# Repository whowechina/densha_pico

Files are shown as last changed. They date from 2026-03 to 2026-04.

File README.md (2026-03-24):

# Densha pico - Densha De Go! Style Controller
[点这里可以切换到中文版](README_CN.md)



It's XXXXX.

## Features
* XXX
* YYY

## Thanks
Thanks to many respectful guys/companies who made their tools or materials free or open source (KiCad, OnShape, InkScape, Raspberry things).

Special thanks to community projects and developers.
And also these projects:
* RP_Silicon_KiCad: https://github.com/HeadBoffin/RP_Silicon_KiCad

## My Other Projects
You can check out my other cool projects.

               


* Popn Pico: https://github.com/whowechina/popn_pico
* IIDX Pico: https://github.com/whowechina/iidx_pico
* Chu Pico: https://github.com/whowechina/chu_pico
* Mai Pico: https://github.com/whowechina/mai_pico
* Diva Pico: https://github.com/whowechina/diva_pico
* AIC Pico: https://github.com/whowechina/aic_pico
* Groove Pico: https://github.com/whowechina/groove_pico
* Geki Pico: https://github.com/whowechina/geki_pico
* Musec Pico: https://github.com/whowechina/musec_pico
* Ju Pico: https://github.com/whowechina/ju_pico
* Bishi Pico: https://github.com/whowechina/bishi_pico
* Nos Pico: https://github.com/whowechina/nos_pico
* Voltex Pico: https://github.com/whowechina/voltex_pico
* Chord Pico: https://github.com/whowechina/chord_pico
* Dance Pico: https://github.com/whowechina/dance_pico
* Densha pico: https://github.com/whowechina/densha_pico

## **Disclaimer** ##
I made this project in my personal time with no financial benefit or sponsorship. I will continue to improve the project. I have done my best to ensure that everything is accurate and functional, there's always a chance that mistakes may occur. I cannot be held responsible for any loss of your time or money that may result from using this open source project. Thank you for your understanding.

## About the License
It's CC-NC. So DIY for yourself and for your friend, don't make money from it. And plagiarism that doesn’t even dare to mention the original author is not acceptable. Please note that pooling orders and group buying for raw materials is acceptable.Selling any leftover components at cost (without profit) is also acceptable.

If you're interested in buying from me, or for commercial use, please contact me (Discord, QQ group, Goofish).
* My Discord Invitation: https://discord.gg/M8f2PPQFEA
* QQ Group: 854535476
* Goofish: whowe12345

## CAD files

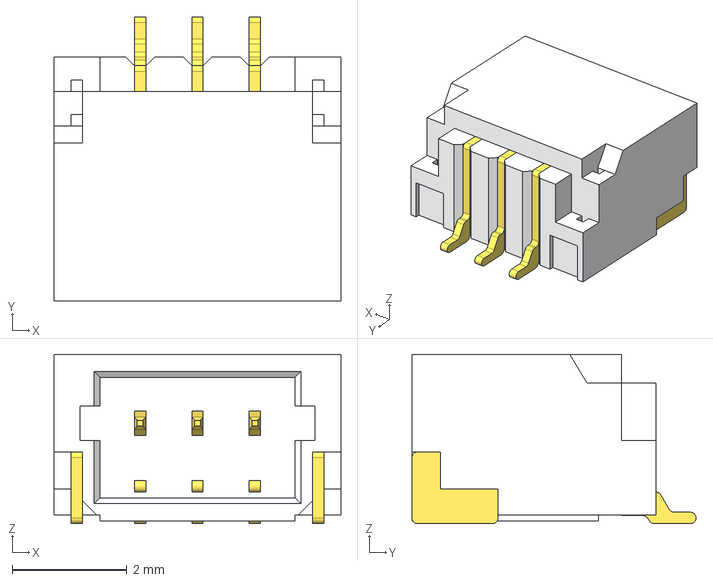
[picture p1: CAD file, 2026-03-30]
PCB/Prototype/3dmodels/SM3B-SRSS-TB.step
5.00 x 4.95 x 2.95 mm

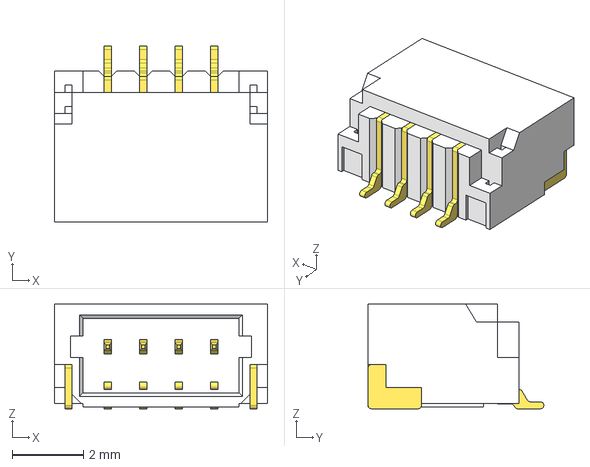
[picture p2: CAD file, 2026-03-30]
PCB/Prototype/3dmodels/SM4B-SRSS-TB.step
6.00 x 4.95 x 2.95 mm

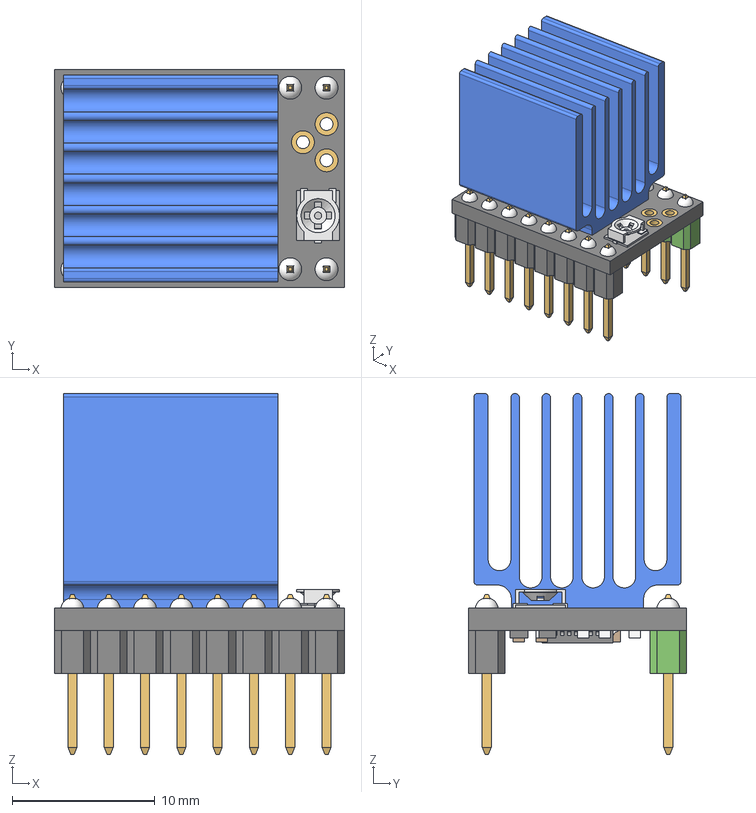
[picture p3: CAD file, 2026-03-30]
PCB/Prototype/3dmodels/TMC2209.step
20.3 x 15.2 x 25.3 mm
Body001 (Mirror #1)
Body001 (Mirror #1)001
Body001 (Mirror #1)002
Body001 (Mirror #1)003
Body001 (Mirror #1)004
Body001 (Mirror #1)005
Body001 (Mirror #1)006
Body001 (Mirror #1)007
Body001 (Mirror #1)008
Body001 (Mirror #1)009
Body001 (Mirror #1)010
Body001 (Mirror #1)011
Body001 (Mirror #1)012
Body001 (Mirror #1)013

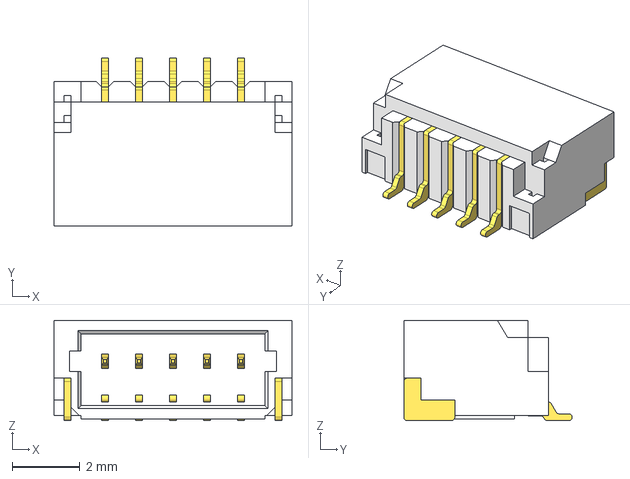
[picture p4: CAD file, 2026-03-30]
PCB/Prototype/3dmodels/SM5B-SRSS-TB.step
7.00 x 4.95 x 2.95 mm

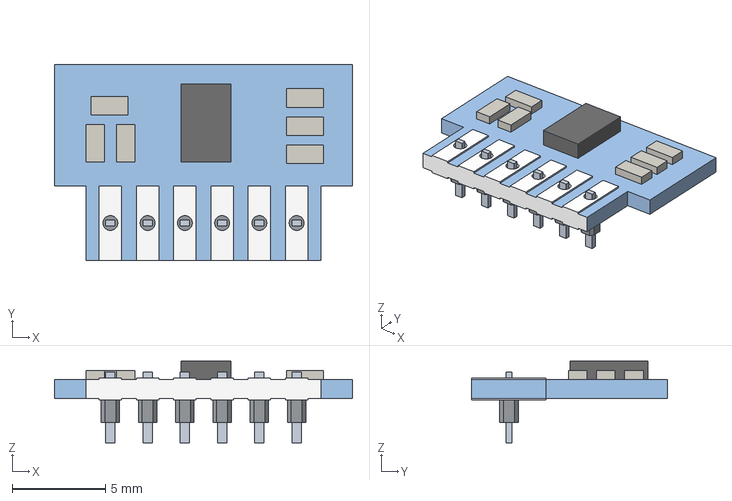
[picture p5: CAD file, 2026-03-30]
PCB/Prototype/3dmodels/8002A.step
16.0 x 10.5 x 4.40 mm

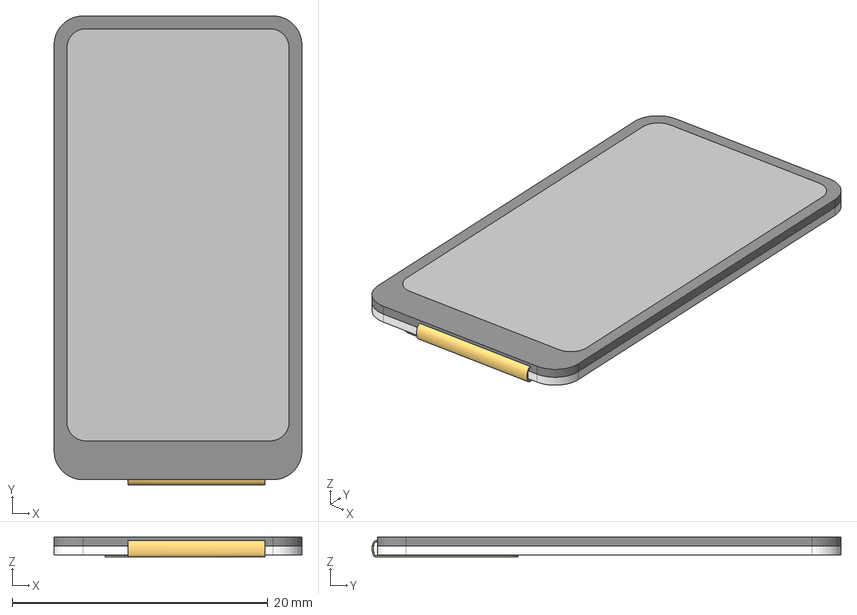
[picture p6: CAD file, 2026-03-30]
PCB/Prototype/3dmodels/IPS LCD 1.47inch ST7789 172x320px.step
19.4 x 36.7 x 1.55 mm

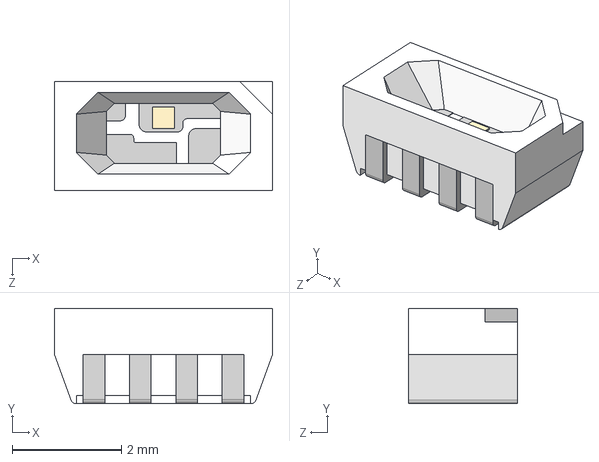
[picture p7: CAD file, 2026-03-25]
PCB/Prototype/3dmodels/User Library-WS2812-4020.step
4.00 x 1.75 x 2.00 mm

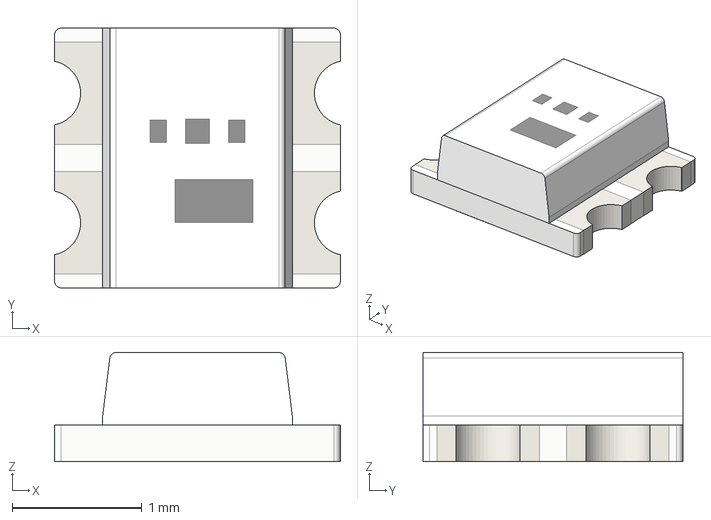
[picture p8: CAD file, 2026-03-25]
PCB/Prototype/3dmodels/LED_WS2812_2020.step
2.20 x 2.00 x 0.842 mm

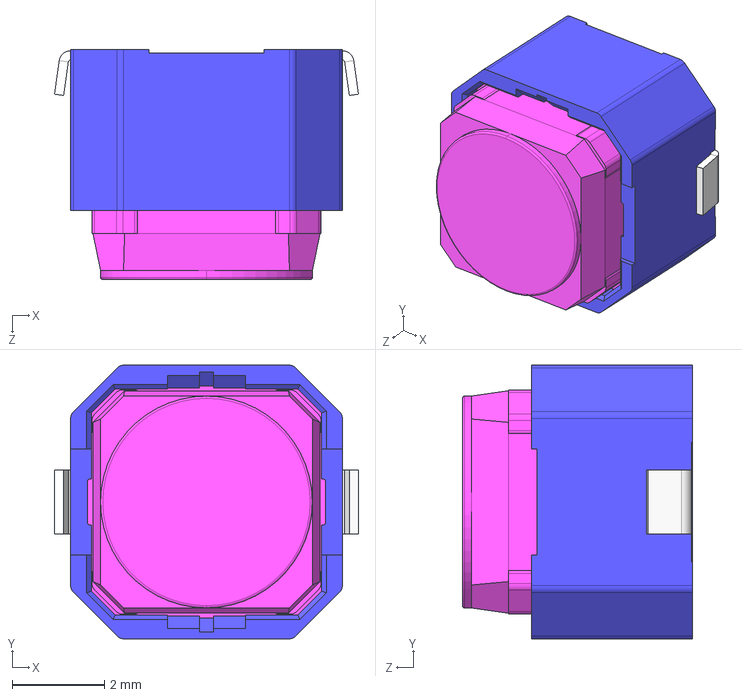
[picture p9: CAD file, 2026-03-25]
PCB/Prototype/3dmodels/SKPMAM.STEP
6.60 x 5.94 x 5.00 mm

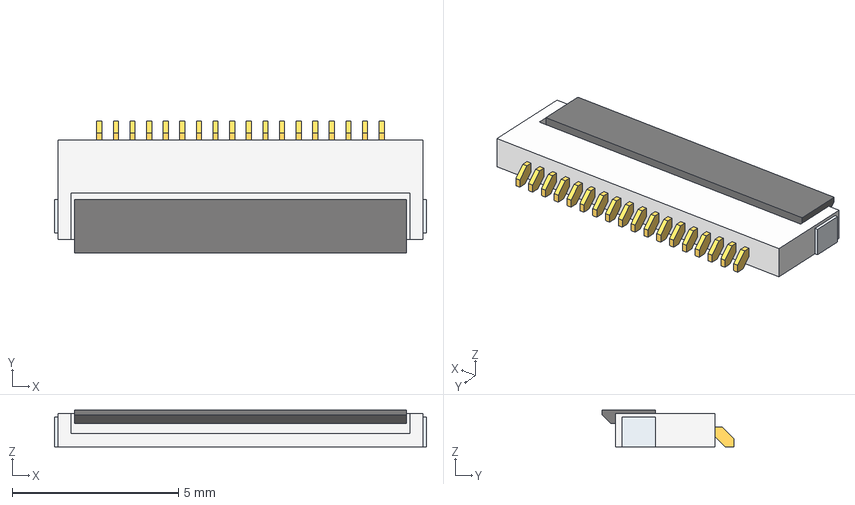
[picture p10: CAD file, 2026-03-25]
PCB/Prototype/3dmodels/FPC0.5MM1.0H18P.step
11.2 x 3.96 x 1.10 mm

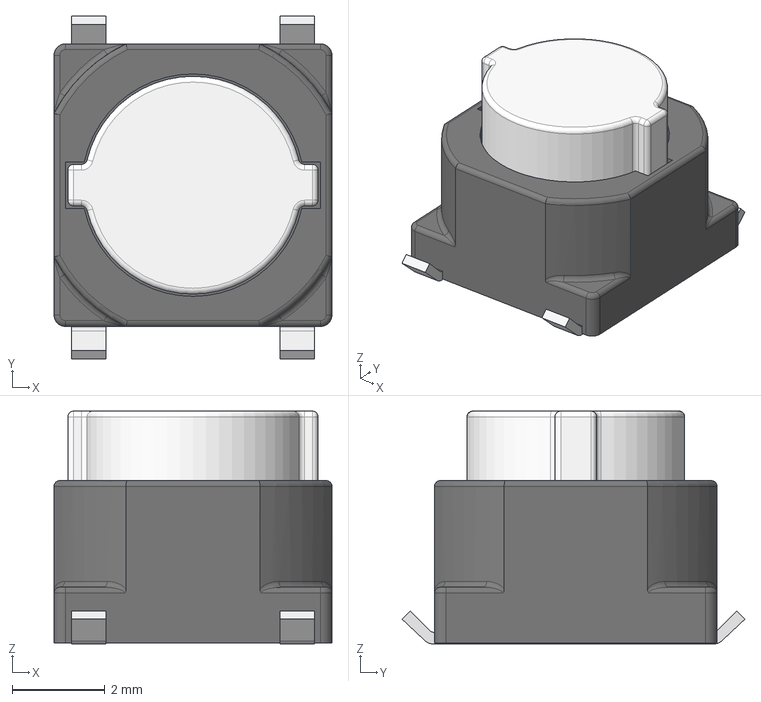
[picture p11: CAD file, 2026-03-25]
PCB/Prototype/3dmodels/EVQ-P1D05M.stp
6.00 x 7.40 x 5.03 mm

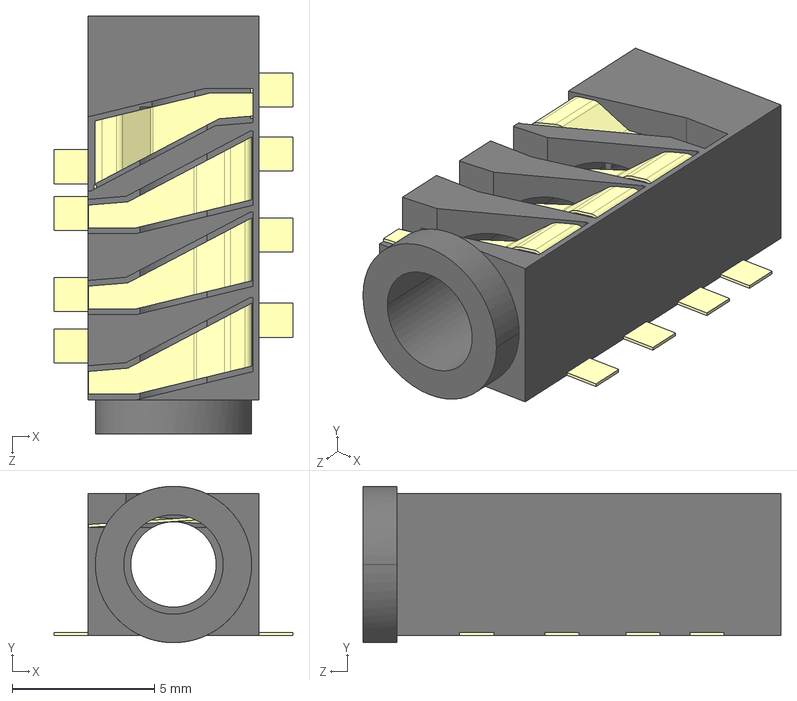
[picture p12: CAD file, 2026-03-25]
PCB/Prototype/3dmodels/User Library-pj-393-8.STEP
8.40 x 5.50 x 14.7 mm
PJ-393-8_1
PJ-393-8_2 x 4
PJ-393-8_3
PJ-393-8_4 x 3

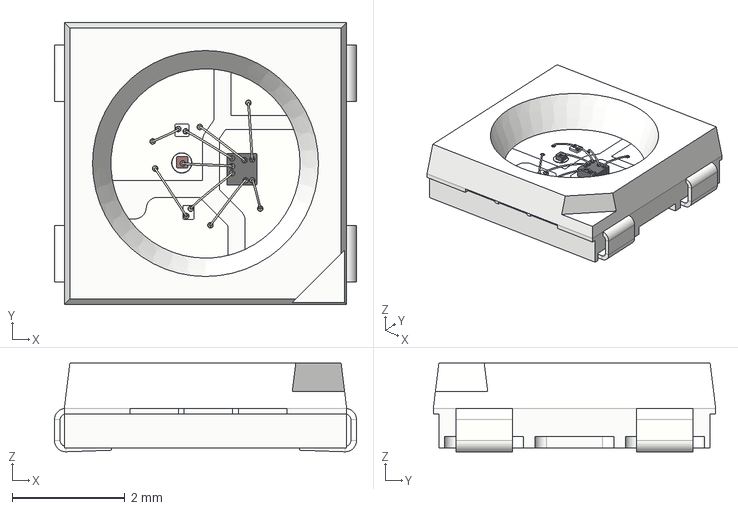
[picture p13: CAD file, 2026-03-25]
PCB/Prototype/3dmodels/WS2812B.step
5.35 x 5.00 x 1.57 mm

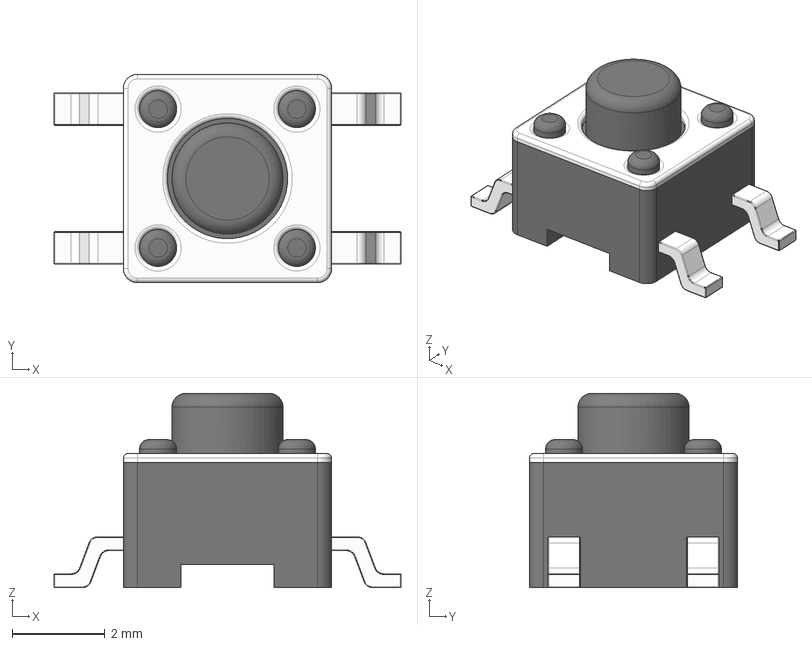
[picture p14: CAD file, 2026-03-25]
PCB/Prototype/3dmodels/Tact Switch 4.5mm SMT.step
7.50 x 4.50 x 4.20 mm

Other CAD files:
PCB/Prototype/3dmodels/SKSTAAE010.stp
PCB/Prototype/3dmodels/WS2812-2020.STEP
PCB/Prototype/3dmodels/User Library-WS2812-2020.step
PCB/Prototype/3dmodels/User Library-PTS645SL95SMTR92-LFS.STEP
PCB/Prototype/3dmodels/FPC0.5MM10P.stp
PCB/Prototype/3dmodels/SKRRABE010.stp
PCB/Prototype/3dmodels/User Library-RGB1204.STEP
PCB/Prototype/3dmodels/WS2812-0807.STEP

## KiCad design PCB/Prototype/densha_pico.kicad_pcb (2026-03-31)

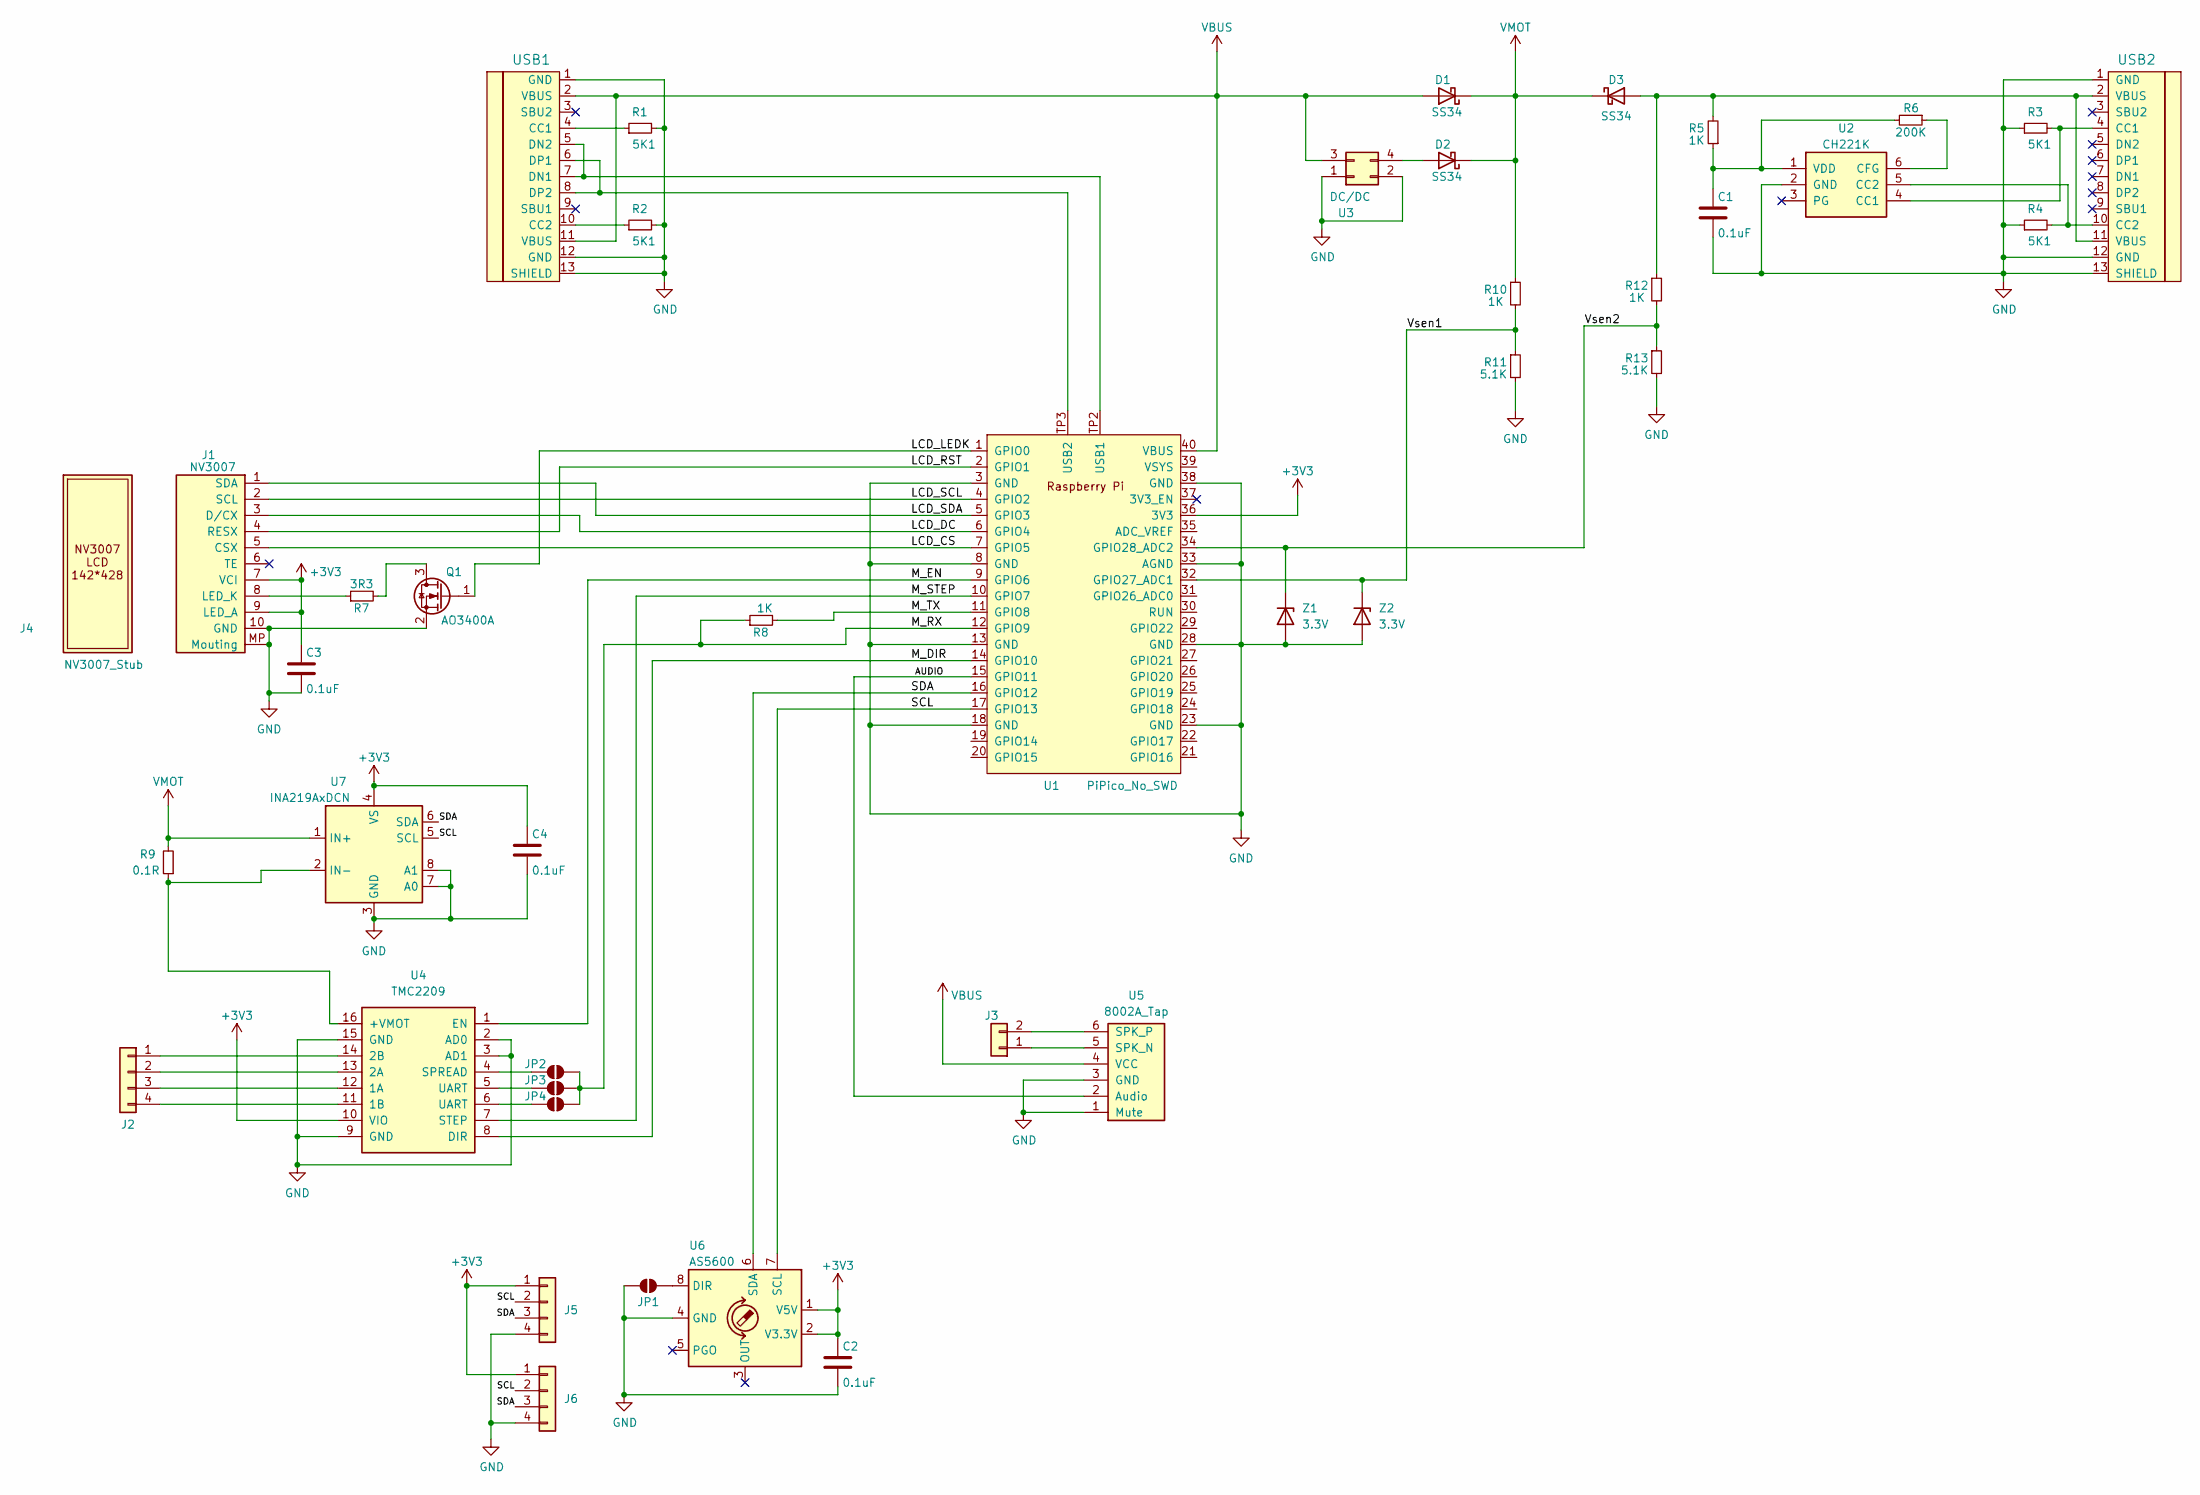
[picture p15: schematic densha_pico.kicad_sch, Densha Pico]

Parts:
C1, C2, C3, C4: 0.1uF; C_0603_1608Metric_Pad1.08x0.95mm_HandSolder
D1, D2, D3: SS34; D_SMA
J1: NV3007; FPC0.5_10P
J2: Conn_01x04; JST_EH_S4B-EH_1x04_P2.50mm_Horizontal
J3: Conn_01x02; Solder_2P
J4: NV3007_Stub
J5, J6: Spin; SH1.0_4P_Solder_Combo
JP1, JP2, JP3, JP4: DIR; SmallJumper
Q1: AO3400A; SOT-23
R1, R2, R3, R4: 5K1; R_0603_1608Metric_Pad0.98x0.95mm_HandSolder; LCSC C23186
R5, R8, R10, R12: 1K; R_0603_1608Metric_Pad0.98x0.95mm_HandSolder; LCSC C23186
R6: 200K; R_0603_1608Metric_Pad0.98x0.95mm_HandSolder; LCSC C23186
R7: 3R3; R_0603_1608Metric_Pad0.98x0.95mm_HandSolder; LCSC C23186
R9: 0.1R; L_1206_3216Metric_Pad1.42x1.75mm_HandSolder; LCSC C23186
R11, R13: 5.1K; R_0603_1608Metric_Pad0.98x0.95mm_HandSolder; LCSC C23186
U1: PiPico_No_SWD; RPi_Pico_SMD_Pins_No_SWD
U2: CH221K; TSOT-23-6_HandSoldering
U3: DC/DC; DCDC_3to5
U4: TMC2209; TMC2209_16P
U5: 8002A_Tap; 8002A_TAP
U6: AS5600; SOIC-8_3.9x4.9mm_P1.27mm
U7: INA219AxDCN; SOT-23-8_Thin
USB1: Data; HRO-TYPE-C-31-M-12-Assembly
USB2: PD; HRO-TYPE-C-31-M-12-Assembly
Z1, Z2: 3.3V; D_SOD-123F

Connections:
+3V3: C2.1, C3.1, C4.1, J1.7 (VCI), J1.9 (LED_A), J5.1, J6.1, U1.36 (3V3), U4.10 (VIO), U6.1 (V5V), U6.2 (V3.3V), U7.4 (VS)
/AUDIO: U1.15 (GPIO11), U5.2 (Audio)
/LCD_CS: J1.5 (CSX), U1.7 (GPIO5)
/LCD_DC: J1.3 (D/CX), U1.6 (GPIO4)
/LCD_LEDK: Q1.1 (G), U1.1 (GPIO0)
/LCD_RST: J1.4 (RESX), U1.2 (GPIO1)
/LCD_SCL: J1.2 (SCL), U1.4 (GPIO2)
/LCD_SDA: J1.1 (SDA), U1.5 (GPIO3)
/M_DIR: U1.14 (GPIO10), U4.8 (DIR)
/M_EN: U1.9 (GPIO6), U4.1 (EN)
/M_RX: JP2.2 (B), JP3.2 (B), JP4.2 (B), R8.1, U1.12 (GPIO9)
/M_STEP: U1.10 (GPIO7), U4.7 (STEP)
/M_TX: R8.2, U1.11 (GPIO8)
/SCL: J5.2, J6.2, U1.17 (GPIO13), U6.7 (SCL), U7.5 (SCL)
/SDA: J5.3, J6.3, U1.16 (GPIO12), U6.6 (SDA), U7.6 (SDA)
/Vsen1: R10.2, R11.1, U1.32 (GPIO27_ADC1), Z2.1 (K)
/Vsen2: R12.2, R13.1, U1.34 (GPIO28_ADC2), Z1.1 (K)
GND: C1.2, C2.2, C3.2, C4.2, J1.10 (GND), J1.MP (Mouting), J5.4, J6.4, JP1.1 (A), Q1.2 (S), R1.2, R2.2, R3.1, R4.1, R11.2, R13.2, U1.3 (GND), U1.8 (GND), U1.13 (GND), U1.18 (GND), U1.23 (GND), U1.28 (GND), U1.33 (AGND), U1.38 (GND), U2.2 (GND), U3.1, U3.2, U4.2 (AD0), U4.3 (AD1), U4.9 (GND), U4.15 (GND), U5.1 (Mute), U5.3 (GND), U6.4 (GND), U7.3 (GND), U7.7 (A0), U7.8 (A1), USB1.1 (GND), USB1.12 (GND), USB1.13 (SHIELD), USB2.1 (GND), USB2.12 (GND), USB2.13 (SHIELD), Z1.2 (A), Z2.2 (A)
unnamed: D2.2 (A), U3.4
unnamed: D3.2 (A), R5.2, R12.1, USB2.2 (VBUS), USB2.11 (VBUS)
unnamed: J1.8 (LED_K), R7.1
unnamed: J2.1, U4.14 (2B)
unnamed: J2.2, U4.13 (2A)
unnamed: J2.3, U4.12 (1A)
unnamed: J2.4, U4.11 (1B)
unnamed: J3.1, U5.5 (SPK_N)
unnamed: J3.2, U5.6 (SPK_P)
unnamed: JP1.2 (B), U6.8 (DIR)
unnamed: JP2.1 (A), U4.4 (SPREAD)
unnamed: JP3.1 (A), U4.5 (UART)
unnamed: JP4.1 (A), U4.6 (UART)
unnamed: Q1.3 (D), R7.2
unnamed: U1.TP2 (USB1), USB1.5 (DN2), USB1.7 (DN1)
unnamed: U1.TP3 (USB2), USB1.6 (DP1), USB1.8 (DP2)
unnamed: R3.2, U2.4 (CC1), USB2.4 (CC1)
unnamed: R4.2, U2.5 (CC2), USB2.10 (CC2)
unnamed: R6.1, U2.6 (CFG)
unnamed: C1.1, R5.1, R6.2, U2.1 (VDD)
unnamed: R9.1, U4.16 (+VMOT), U7.2 (IN-)
unnamed: R1.1, USB1.4 (CC1)
unnamed: R2.1, USB1.10 (CC2)
VBUS: D1.2 (A), U1.40 (VBUS), U3.3, U5.4 (VCC), USB1.2 (VBUS), USB1.11 (VBUS)
VMOT: D1.1 (K), D2.1 (K), D3.1 (K), R9.2, R10.1, U7.1 (IN+)

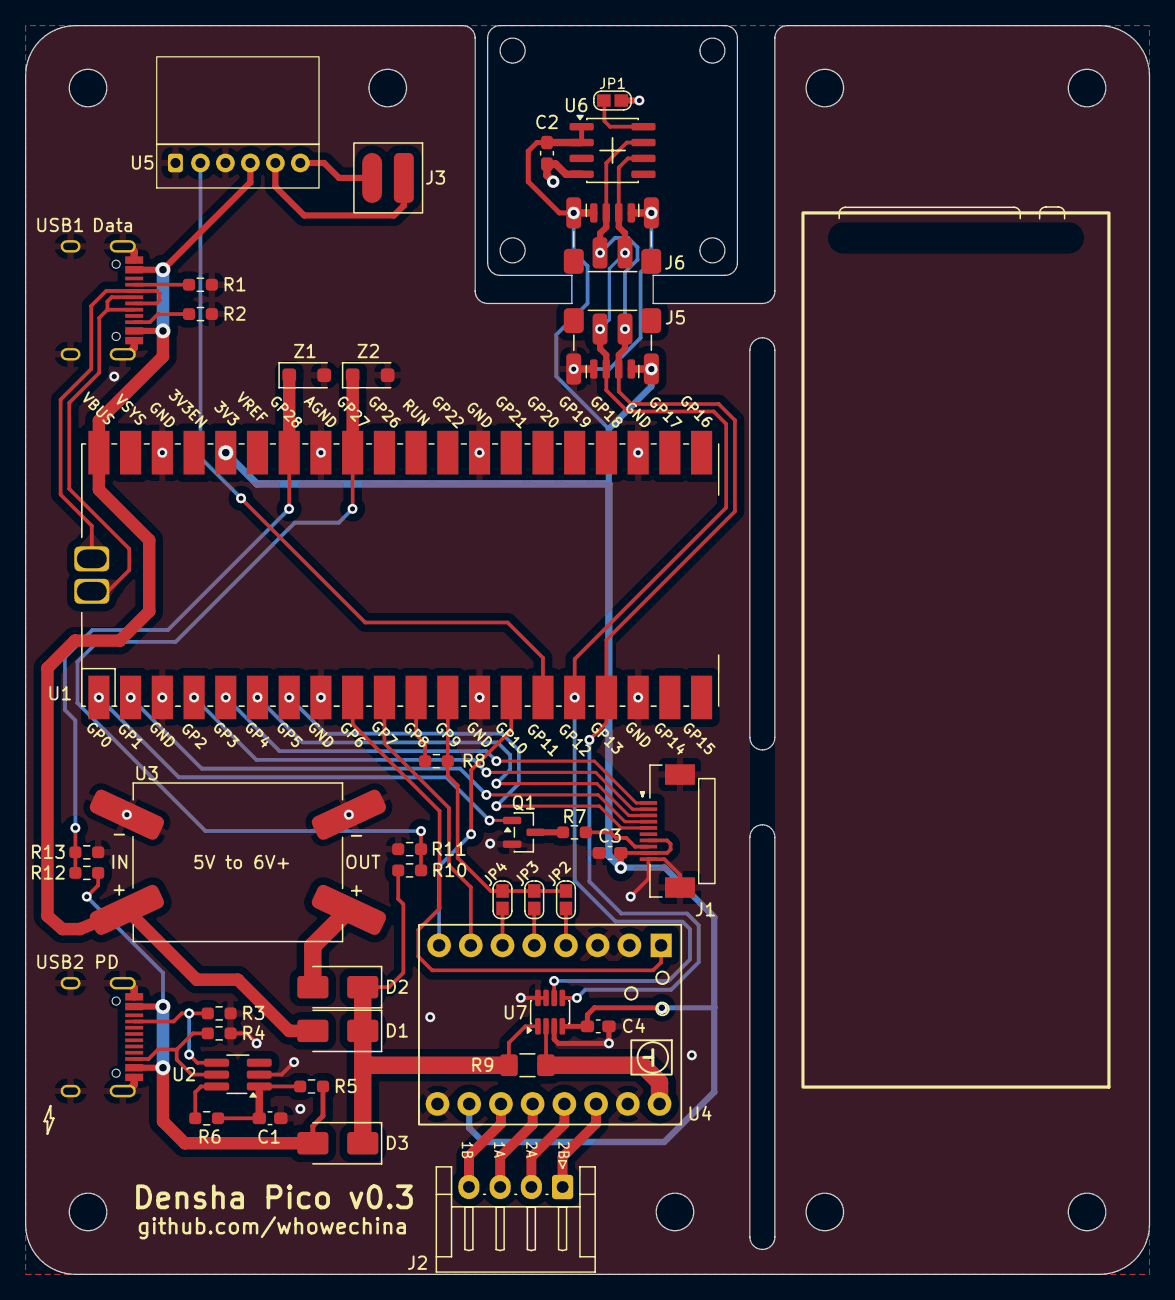
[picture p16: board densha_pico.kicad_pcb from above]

Board: 2 copper layers, 90.0 x 100.0 mm, 42 parts (0 on the bottom side), 43 nets.

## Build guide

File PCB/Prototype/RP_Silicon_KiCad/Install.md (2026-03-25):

# Install KiCad libraries

## Manage Symbol Libraries

Accessed from the Preferences menu, add a new line with the +, give it a name and use the folder icon to point to the directory/folder where you have KiCadLibraries.

Manage Symbol Libraries screen shot


## Manage Footprint Libraries

Ditto! Accessed from the Preferences menu, add a new line with the +, give it a name and use the folder icon to point to the directory/folder where you have KiCadLibraries.

Manage Footprint Libraries screen shot


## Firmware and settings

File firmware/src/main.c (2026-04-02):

/*
 * Controller Main
 * WHowe <github.com/whowechina>
 */

#include <stdlib.h>
#include <stdint.h>
#include <stdbool.h>

#include "pico/stdio.h"
#include "pico/stdlib.h"
#include "bsp/board.h"
#include "pico/multicore.h"
#include "pico/bootrom.h"


#include "hardware/clocks.h"
#include "hardware/gpio.h"
#include "hardware/sync.h"
#include "hardware/structs/ioqspi.h"
#include "hardware/structs/sio.h"

#include "tusb.h"
#include "usb_descriptors.h"

#include "board_defs.h"

#include "savedata.h"
#include "config.h"
#include "cli.h"
#include "commands.h"

#include "light.h"
#include "button.h"

#include "lever.h"
#include "nv3007.h"

#include "gui.h"

const bool gui = true;
const bool lever = true;

static void run_lights()
{
    uint16_t button = button_read();
    switch (button & 0x03) {
        case 0x01:
            light_set(0, rgb32(0, 255, 0, false), false);
            break;
        case 0x02:
            light_set(0, rgb32(160, 0, 0, false), false);
            break;
        default:
            light_set(0, rgb32(2, 2, 2, false), false);
            break;
    }
}

static void core1_init()
{
    flash_safe_execute_core_init();
}

static void core1_loop()
{
    core1_init();

    while (1) {
        run_lights();
        light_update();
        if (gui) gui_loop();
        cli_fps_count(1);
        sleep_us(700);
    }
}

struct __attribute__((packed)) {
    uint8_t buttons;
    uint8_t padding;
} hid_report, hid_report_sent;

static void hid_update()
{
    hid_report.buttons = button_read();

    static uint64_t last_report_time = 0;
    if (tud_hid_ready()) {
        uint64_t now = time_us_64();
        if ((memcmp(&hid_report, &hid_report_sent, sizeof(hid_report)) == 0) &&
            (now - last_report_time < 10000)) {
            return;
        }
        last_report_time = now;
        if (tud_hid_report(REPORT_ID_JOYSTICK, &hid_report, sizeof(hid_report))) {
            hid_report_sent = hid_report;
        }
    }
}

static void debug_display()
{
    static uint64_t last_display = 0;
    uint64_t now = time_us_64();
    if (now - last_display < 100000) {
        return;
    }
    last_display = now;
}

static void core0_loop()
{
    uint64_t next_frame = 0;
    while(1) {
        tud_task();

        cli_run();

        savedata_loop();
        cli_fps_count(0);

        //button_update();

        hid_update();

        if (lever) lever_update();

        debug_display();

        sleep_until(next_frame);
        next_frame += 1000;
    }
}

/* if certain key pressed when booting, enter update mode */
static void update_check()
{
}

void init()
{
    sleep_ms(50);

    set_sys_clock_khz(240000, true);

    board_init();
    update_check();

    tusb_init();
    stdio_init_all();

    config_init();
    savedata_init(0xcaf1ccc2);

    light_init();
    //button_init();

    if (lever) lever_init();

    gui_init();

    cli_init("densha_pico>", "\n   << Densha pico Controller >>\n"
                            " https://github.com/whowechina\n\n");
    
    commands_init();
}

int main(void)
{
    init();

    multicore_launch_core1(core1_loop);
    core0_loop();
    return 0;
}

// Invoked when received GET_REPORT control request
// Application must fill buffer report's content and return its length.
// Return zero will cause the stack to STALL request
uint16_t tud_hid_get_report_cb(uint8_t itf, uint8_t report_id,
                               hid_report_type_t report_type, uint8_t *buffer,
                               uint16_t reqlen)
{
    printf("Get from USB %d-%d\n", report_id, report_type);
    return 0;
}

// Invoked when received SET_REPORT control request or
// received data on OUT endpoint ( Report ID = 0, Type = 0 )
void tud_hid_set_report_cb(uint8_t itf, uint8_t report_id,
                           hid_report_type_t report_type, uint8_t const *buffer,
                           uint16_t bufsize)
{
    if ((report_id == REPORT_ID_LIGHTS) && (bufsize >= 24)) {
        for (int i = 0; i < 8; i++) {
            const uint8_t *rgb = &buffer[i * 3];
            uint32_t color = rgb32(rgb[0], rgb[1], rgb[2], false);
            light_set(i, color, true);
        }
    }
}

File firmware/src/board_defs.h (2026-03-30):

/*
 * Densha pico Board Definitions
 * WHowe <github.com/whowechina>
 */

#if defined BOARD_DENSHA_PICO

#define RGB_PIN 16

#define RGB_ORDER GRB // or RGB

#define BUTTON_GPIO { 28, 15 }
#define BUTTON_PULL_UPDOWN {  }

#define TMC2209_ENABLE_PIN 6
#define TMC2209_STEP_PIN 7
#define TMC2209_DIR_PIN 10

#define TMC2209_UART uart1
#define TMC2209_TX_PIN 8
#define TMC2209_RX_PIN 9

#define SENSOR_I2C i2c0
#define SENSOR_SCL_PIN 13
#define SENSOR_SDA_PIN 12

#define NV3007_SPI spi0
#define NV3007_SCK_PIN 2
#define NV3007_TX_PIN 3
#define NV3007_CSN_PIN 5
#define NV3007_DC_PIN 4
#define NV3007_RST_PIN 1
#define NV3007_LEDK_PIN 0

#endif

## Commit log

2026-03-25 Prototype PCB progress 40%
    [8002A.step, EVQ-P1D05M.stp, FPC0.5MM1.0H18P.step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]
2026-03-30 Firmware works on PCB with Pico 2
2026-03-30 PCB v0.2
    [8002A.step, IPS LCD 1.47inch ST7789 172x320px.step, SM3B-SRSS-TB.step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]
2026-03-31 PCB v0.3
    [densha_pico.kicad_pcb, densha_pico.kicad_sch]
2026-04-02 Mascon current set and debug
